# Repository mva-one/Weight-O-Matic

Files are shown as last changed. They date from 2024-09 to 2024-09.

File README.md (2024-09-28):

# Was ist Weight-O-Matic?
Weight-O-Matic ist ein kompaktes, einfach zu bedienendes, mikrocontrollergesteuertes Hilfsmittel auf Basis des AtMega 328P (Arduino Nano), um Prozesse, bei denen die Masse eines Objektes zunimmt, bei einem entsprechenden Soll-Wert anzuhalten. Es wurde speziell für den Anwendungsfall entwickelt, die Produktion einer Leitungswasser-Osmoseanlage anzuhalten, nachdem ein entsprechender Kanister am Ausgang vollständig gefüllt wurde.  

Das System bietet die Möglichkeit, das Gewicht des Wasserkanisters mittels einer Waage zu überwachen und entsprechend eines Sollwertes einen elektrischen Ausgang anzusteuern. In diesem Anwendungsfall ist an den Ausgang ein (stromlos geschlossenes) Magnetventil angeschlossen, welches den Wasserausgang der Osmoseanlage schließt - wodurch sich diese ausschaltet.

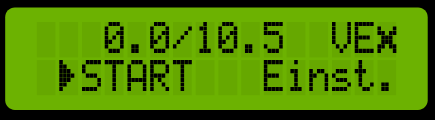
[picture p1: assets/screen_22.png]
Startbildschrim


***Hinweis:** Das Projekt ist aktuell noch Work-In-Progess! Es könnten noch weitreichende Änderungen erfolgen.*

# Was ist in diesem Repo?
Hier befinden sich alle Projektdateien:
- Im Unterordner `Weight-O-Matic_FW` ist das PlatformIO-Projekt für die Firmware des Mikrocontrollers zu finden.
<!-- - Der Ordner `Bedienungsanleitung` beinhaltet ebendiese als pdf-Datei. Ist noch ziemlich unvollständig. -->
- Unter `Zustandsdiagramm` ist die [abstrakte Darstellung der Menüzustände](Zustandsdiagramm/state_diagram.png) im PlantUML-Format und als PNG zu finden.
- Im Ordner `Weight-O-Matic_HW` befindet sich der Schaltplan (KiCad-Projekt) bzw. weitere Informationen zur verwendeten Hardware.
- `assets` beinhaltet alle Artefakte, die von diesem Readme oder in der Bedienungsanleitung eingebunden werden.

# Wie kann man das ausprobieren?

Mit [Wokwi](https://wokwi.com/) kann Weight-O-Matic simuliert werden, um es auch ohne Hardware ausprobieren zu können!

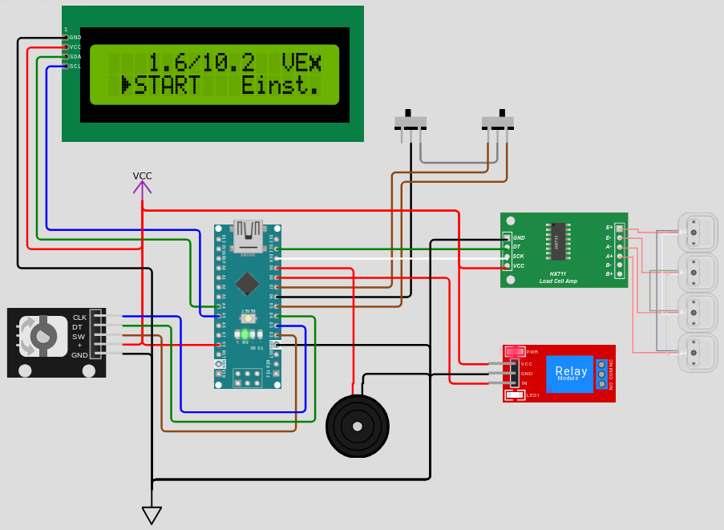
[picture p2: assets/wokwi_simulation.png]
Simulation mit Wokwi


Link: https://wokwi.com/projects/409734208353140737

**Hinweise zur Simulation mit Wokwi**:
- Manchmal wird beim Starten der Simulation ein Fehler angezeigt, da die Verbindung mit der simulierten Wiegezelle nicht hergestellt werden kann. In diesem Fall hilft das Drücken des Reset-Buttons auf dem Arduino Nano.
- Da Wokwi keine 3-Positionen-Schalter zur Verfügung stellt, ist der VE-Wahlschalter durch zwei separate Schalter dargestellt. Der linke wählt, ob eine VE aktiviert werden soll, der rechte Schalter wählt dann zwischen den zwei VE.
- Beim ersten Starten ist das EEPROM im Simulator nicht richtig initialisiert. Dann werden sinnlose Zahlen bei den Voreinstellungen als Tara-Versatz bzw. Sollwert angezeigt. In diesem Fall bitte einmal über das Einstellungsmenü den Punkt "RST" wählen, um das simulierte EEPROM mit den Standardwerten zu überschreiben. Da das danach folgende Software-Reset des Mikrocontrollers in der Simulation nicht funktioniert, ist der Reset-Button auf dem Arduino Nano zu betätigen!
- Die Standardwerte für die Kalibrierung der Waage sind für die Simulation ungeeignet. Am besten deshalb nach dem soeben beschriebenen Reset auch direkt eine Kalibrierung vornehmen!

# Lizenz

Siehe [LICENSE](LICENSE)!

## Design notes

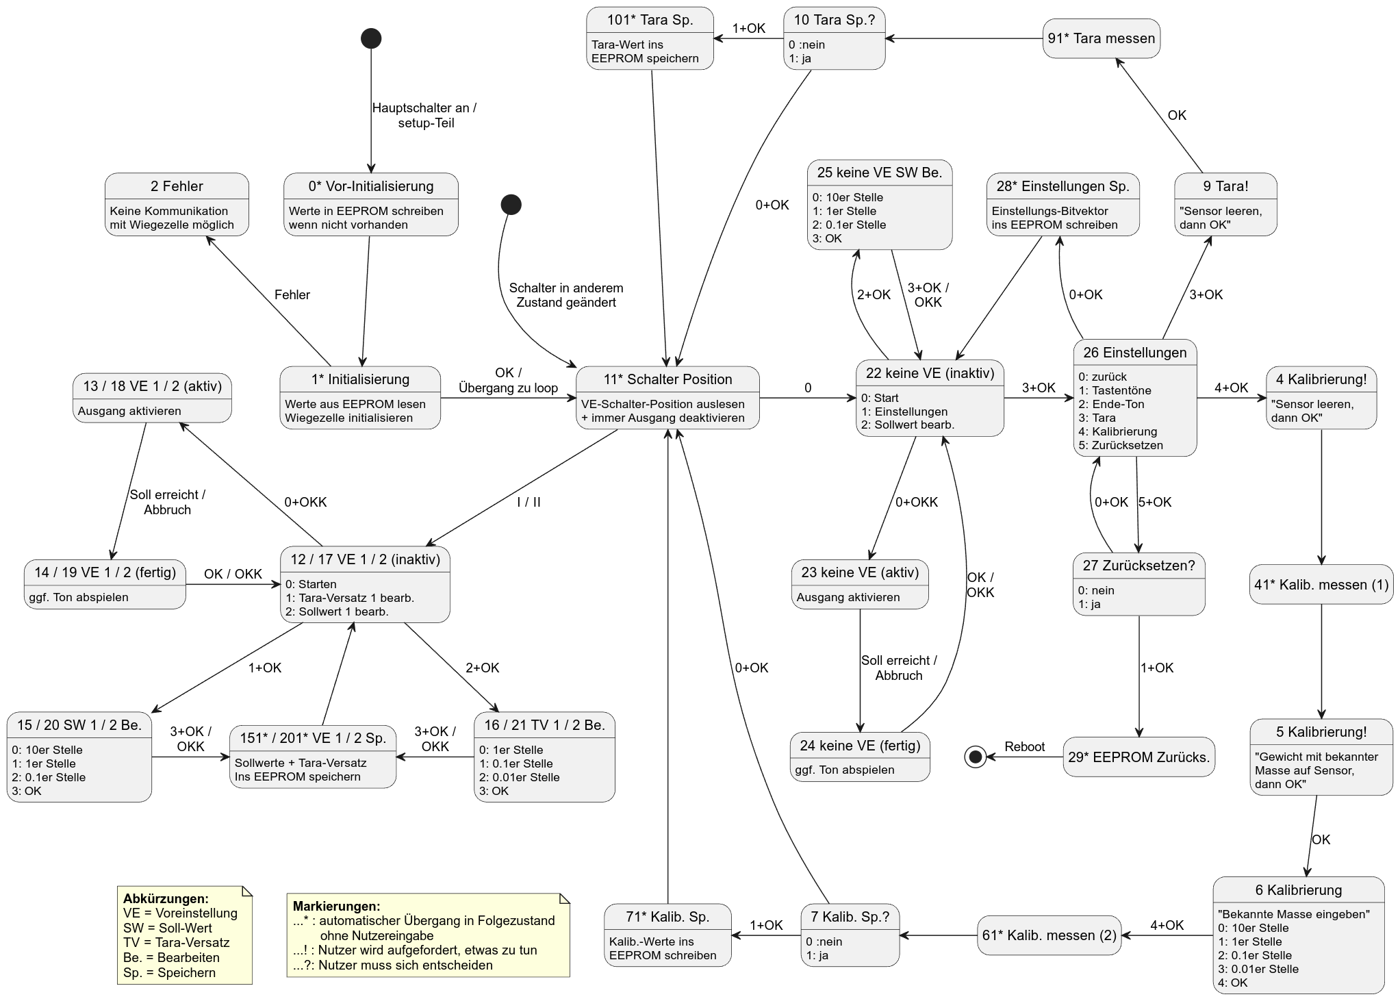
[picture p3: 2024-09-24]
Zustandsdiagramm/state_diagram.png

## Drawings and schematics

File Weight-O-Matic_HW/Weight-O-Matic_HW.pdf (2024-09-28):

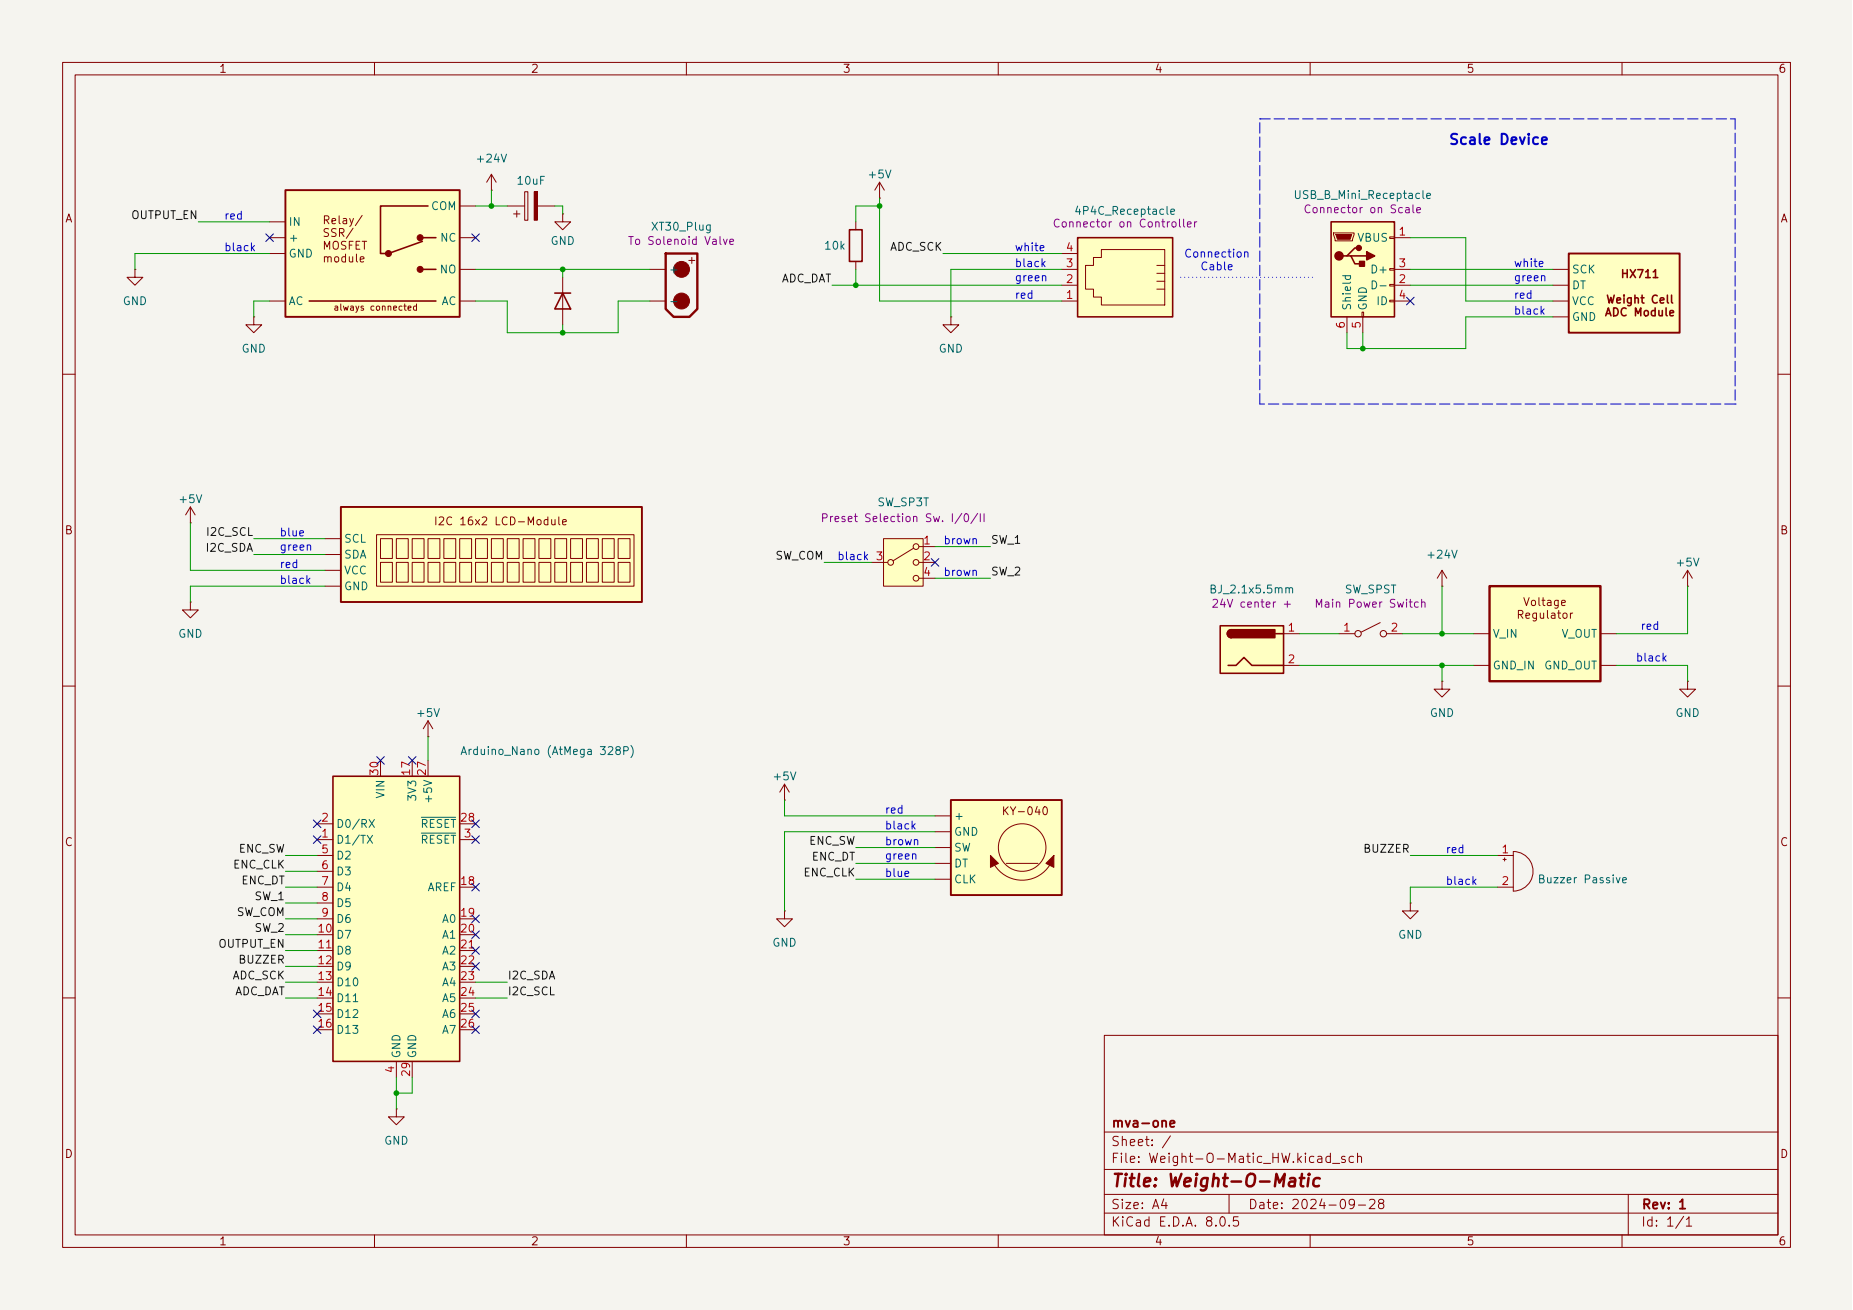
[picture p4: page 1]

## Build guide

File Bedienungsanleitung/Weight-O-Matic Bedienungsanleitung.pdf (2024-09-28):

# Weight-O-Matic Bedienungsanleitung Weight-O-Matic - Bedienungsanleitung

## 1 - Was ist Weight-O-Matic?

Weight-O-Matic ist ein kompaktes, einfach zu bedienendes Hilfsmittel, um Prozesse, bei denen die Masse eines Objektes zunimmt, bei einem entsprechenden Soll-Wert anzuhalten. Es wurde speziell für den Anwendungsfall entwickelt, die Produktion einer Leitungswasser-Osmoseanlage anzuhalten, nachdem ein entsprechender Kanister am Ausgang vollständig gefüllt wurde.

Das System bietet die Möglichkeit, das Gewicht des Wasserkanisters mittels einer Waage zu überwachen und entsprechend eines Sollwertes einen elektrischen Ausgang anzusteuern. In diesem Anwendungsfall ist an den Ausgang ein (stromlos geschlossenes) Magnetventil angeschlossen, welches den Wasserausgang der Osmoseanlage schließt - wodurch sich diese ausschaltet.

Im weiteren Verlauf der Anleitung wird dieser Anwendungsfall beschrieben.

## 2 - Komponentenübersicht

Das System besteht aus der Waage, dem Steuergerät und dem Magnetventil, sowie der dazugehörigen Anschlussleitungen.

## 2.1 Waage

Die Waage ist eine modifizierte handelsübliche Personenwaage. Das originale LC-Display der Waage hat keine Funktion. Auf der Unterseite befindet sich der Anschluss zur Verbindung mit dem Steuergerät: hierfür ist ausschließlich das beigelegte Kabel mit Mini-USB-Verbindern auf Seite der Waage und 4P/4C-Klickverbindern am Steuergerät

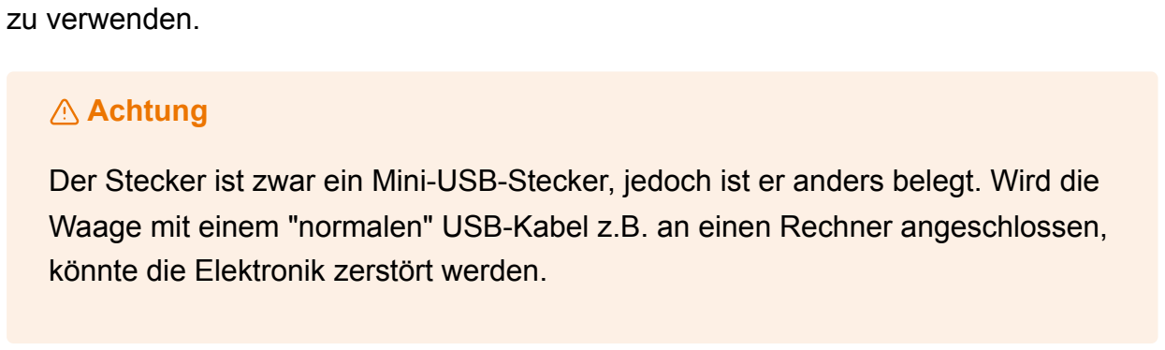
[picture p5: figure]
zu verwenden.; Achtung; könnte die Elektronik zerstört werden.

Der Stecker ist zwar ein Mini-USB-Stecker, jedoch ist er anders belegt. Wird die Waage mit einem "normalen" USB-Kabel z.B. an einen Rechner angeschlossen,

## 2.2 Steuergerät

Das Steuergerät ist die zentrale Komponente der Anlage. Zur Interaktion mit dem Nutzer stehen folgende Komponenten zur Verfügung:

Folgende Anschlüsse befinden sich am Steuergerät:

Seite | Typ | Verwendung
links | DC-Hohlstecker, 2.1x5.5mm | Stromversorgung der Anlage mit 24V DC (+ innen, -außen)
hinten | XT30-Stecker | Ausgang und Verbindung zum Magnetventil (24V DC)
hinten | 4C/4P "RJ-Stecker" | Verbindung zur Waage

## 3 - Funktionsprinzip

Das Grundprinzip ist einfach. Nach der Ersteinstellung (Kalibrierung, Tara-Versätze, Sollwerte) wird die gewünschte Voreinstellung gewählt, der Wasserkanister auf die Waage gestellt und das System gestartet. Dann lässt es so lange den Kanister auf der Waage befüllen, bis die Soll-Füllmenge erreicht wurde und spielt dann - wenn aktiviert
- eine kleine Melodie.

## 3.0 Menü-Navigation

Das Menüsystem von Weight-O-Matic ist so aufgebaut, dass es intutiv mithilfe des Dreh-Drück-Schalters bedient werden kann. Drehen bewegt den Cursor, um einen Menüpunkt auszuwählen und ein Klick aktiviert ihn. Bei Zahleneingaben erhöht bzw. verringert das Drehen die entsprechende Stelle der bearbeiteten Zahl und ein Klick fährt zur nächsten Stelle fort.

## 3.1 Voreinstellungen

Mit dem Voreinstellungs-Wahlschalter kann zwischen den zwei Voreinstellungen gewählt werden. Diese sind für zwei verschiedene Kanister(größen) vorgesehen. Pro

Ein-/Ausschalter
Voreinstellungs-Wahlschalter: siehe 3.1
Dreh-Drück-Knopf: dient der Navigation in allen Menüs. Kann kurz oder lang gedrückt werden, um verschiedene Funktionen auszulösen
LCD-Anzeige

Voreinstellung lässt sich ein Tara-Versatz im System speichern - das Leergewicht des Kanisters. Außerdem speichert Weight-O-Matic pro Voreinstellung die maximale Füllmenge des Kanisters.

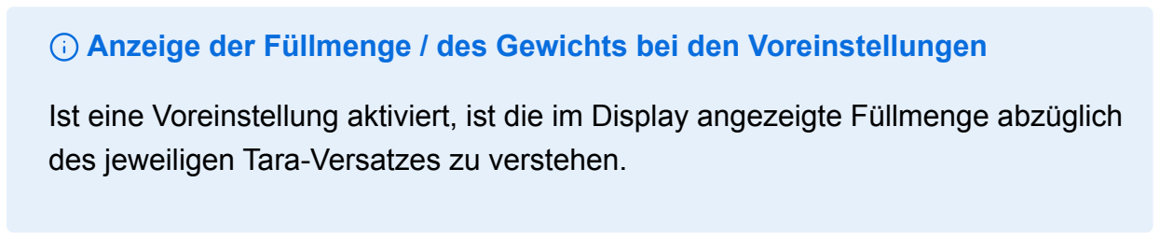
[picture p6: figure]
des jeweiligen Tara-Versatzes zu verstehen.

Wird eine Voreinstellung gestartet, sorgt Weight-O-Matic dafür, dass im Kanister so viel Wasser ist, wie im Soll-Füllwert angegeben. Insbesondere heißt das, dass die Voreinstellungen auch genutzt werden können, um Kanister bis zum Soll-Füllwert zu füllen, auch wenn diese nicht leer sind.

Voreinstellungen bearbeiten:
Es wird immer die Voreinstellung bearbeitet, die gerade durch den Voreinstellungs-Wahlschalter ausgewählt ist. Pro Voreinstellung kann der Sollwert und der Tara-Versatz, wie unter 3.0 beschrieben, bearbeitet werden.

Voreinstellung starten (aktivieren):
Weight-O-Matic kann aktiviert werden, indem der Menücursor auf "starten" bewegt wird und der Dreh-Drück-Taster lange gedrückt wird.

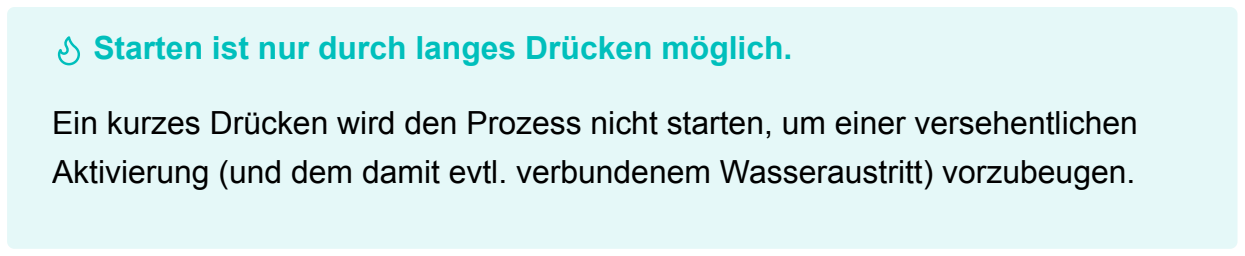
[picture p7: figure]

## 3.2 Keine Voreinstellung

Ist keine Voreinstellung gewählt (VE-Wahlschalter in Position "0"), so gibt es keinen Tara-Versatz, sondern nur einen Sollwert für den Füllprozess.

## 3.3 Füllprozess abbrechen oder beenden

Ist der Füllprozess aktiv, beendet sich dieser selbstständig, sobald der Sollwert erreicht ist. Bei Bedarf kann der Prozess auch durch Klicken des Dreh-Drück-Schalters abgebrochen werden.

In beiden Fällen wird anschließend eine Zusammenfassung angezeigt, wie viel Füllmenge erreicht wurde und wie lange der Prozess gedauert hat.

Anzeige der Füllmenge / des Gewichts bei den Voreinstellungen

Ist eine Voreinstellung aktiviert, ist die im Display angezeigte Füllmenge abzüglich

Starten ist nur durch langes Drücken möglich.

Ein kurzes Drücken wird den Prozess nicht starten, um einer versehentlichen Aktivierung (und dem damit evtl. verbundenem Wasseraustritt) vorzubeugen.

## 4 - Einstellungen

Die Einstellungen sind nur erreichbar, wenn keine Voreinstellung gewählt ist (VE-Wahlschalter in Position "0").

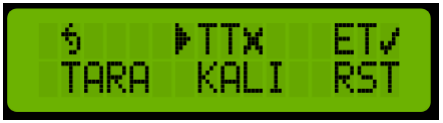
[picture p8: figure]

Das Einstellungsmenü bietet folgende Möglichkeiten:

TT aktiv / inaktiv: Tastentöne (Piepsen) ein- bzw. ausschalten
ET aktiv / inaktiv: Melodie beim erreichen des Sollwertes abspielen bzw. nicht abspielen
TARA: Waage Tarieren (ACHTUNG: Diese Tarierung gilt auch für die Voreinstellungen, bei denen zusätzlich noch der jeweils eingestellte Tara-Versatz hinzugerechnet wird)
KALI: Waage Kalibrieren. Hierzu werden die weiteren Schritte im Display angezeigt.
RST: Alle gespeicherten Einstellungen (auch Kalibrierungs- und Tara-Werte) auf die Standardwerte zurücksetzen. Dies ist normalerweise nicht nötig.

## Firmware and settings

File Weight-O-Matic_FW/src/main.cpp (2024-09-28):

/* MIT License

Copyright (c) 2024 mva-one

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
THE SOFTWARE IS PROVIDED "AS IS", WITHOUT WARRANTY OF ANY KIND, EXPRESS OR
IMPLIED, INCLUDING BUT NOT LIMITED TO THE WARRANTIES OF MERCHANTABILITY,
FITNESS FOR A PARTICULAR PURPOSE AND NONINFRINGEMENT. IN NO EVENT SHALL THE
AUTHORS OR COPYRIGHT HOLDERS BE LIABLE FOR ANY CLAIM, DAMAGES OR OTHER
LIABILITY, WHETHER IN AN ACTION OF CONTRACT, TORT OR OTHERWISE, ARISING FROM,
OUT OF OR IN CONNECTION WITH THE SOFTWARE OR THE USE OR OTHER DEALINGS IN THE
SOFTWARE.
 */

#include <Arduino.h>
#include <HX711_ADC.h>
#include <EEPROM.h>
#include <LCD_I2C.h>
#include <Wire.h>
#include <CtrlBtn.h>
#include <CtrlEnc.h>

#define VERSION F("v0.8")

#define PIN_BEEP 9              // 9 <-(rot)-> Piepser
#define PIN_SW_1 5              // 5 <-(braun)-> Schalter 'I'
#define PIN_SW_COM 6            // 6 <-(schwarz)-> Schalter Common
#define PIN_SW_2 7              // 7 <-(braun)-> Schalter 'II'
#define PIN_OUTPUT 8            // 8 <-(rot)-> Schaltmodul
#define PIN_HX711_DAT 11        // 11 <-(grün)-> DT HX711
#define PIN_HX711_SCK 10        // 10 <-(weiß)-> SCK HX711
#define PIN_ENCODER_CLK 3       // 3 <-(blau)-> CLK Dreh/Drückschalter
#define PIN_ENCODER_DAT 4       // 4 <-(grün)-> DAT Dreh/Drückschalter
#define PIN_ENCODER_BTN 2       // 2<-(braun)-> SW Dreh/Drückschalter
// I2C Pins sind default:       // A5 <-(blau)-> SCL     A4 <-(grün)-> SDA  

// Tonhöhen und -Längen für Tastentöne
#define BEEP_FREQ_LEFT 1350
#define BEEP_FREQ_RIGHT 1100
#define BEEP_FREQ_CLICK 925
#define BEEP_FREQ_ERR 440
#define BEEP_LENGTH_TURN 15
#define BEEP_LENGTH_SHORT 40
#define BEEP_LENGTH_LONG 250
#define BEEP_LENGTH_ERR 300

// Tonhöhen in Hz und "Takt" für Ende-Melodie
#define BEEP_FREQ_A5 880
#define BEEP_FREQ_F5 698
#define BEEP_FREQ_G5 784
#define BEEP_FREQ_B5 932
#define BEEP_UNIT_LENGTH 62
#define BEEP_END_REPETITIONS 4  // Wiederholungen der Ende-Melodie -> bei 4 Wiederholungen wird 5mal abgespielt

// Debug-Ausgaben über die Serielle Konsole aktivieren (Baud 115200)
#define SERIAL_ENABLED

// Standardwerte, werden bei leerem EEPROM geladen (z.B. auch nach dem Zurücksetzen über das Menü)
#define DEFAULT_WEIGHT_TARGET_NO_PRESET 4200
#define DEFAULT_CAL_FACTOR 28.44
#define DEFAULT_TAR_OFFSET 8240259
#define DEFAULT_P1_TARGET 5000
#define DEFAULT_P1_OFFSET 1000
#define DEFAULT_P2_TARGET 10000
#define DEFAULT_P2_OFFSET 2000
#define DEFAULT_TOGGLESETTINGS 0b11000000

#define MAX_WEIGHT_CALIB 99990
#define MIN_WEIGHT_CALIB 10
#define MAX_WEIGHT_SETPOINT 99990
#define MIN_WEIGHT_SETPOINT 100
#define MIN_WEIGHT_OFFSET 0
#define MAX_WEIGHT_OFFSET 9990

#define SETTINGS_KEYTONE 7
#define SETTINGS_ENDTONE 6


// EEPROM-Adressen für verschiedene Einstellungen:
const uint16_t addr_cal_value = 0x10;   // data type: float (4 bytes)  - addr. 0x10 - 0x13
const uint16_t addr_tar_value = 0x14;   // data type: long  (4 bytes)  - addr. 0x14 - 0x17
const uint16_t addr_saved_flag = 0x18;  // data type: bool  (1 byte)   - addr. 0x18

const uint16_t addr_p1_target = 0x20;       // stores long (4B) - addr. 0x20 - 0x23
const uint16_t addr_p1_offset = 0x24;       // stores long (4B) - addr. 0x24 - 0x27
const uint16_t addr_p1_saved_flag = 0x28;   // stores bool (1B) - addr. 0x28

const uint16_t addr_p2_target = 0x29;       // stores long (4B) - addr. 0x29 - 0x2c
const uint16_t addr_p2_offset = 0x2d;       // stores long (4B) - addr. 0x2d - 0x30
const uint16_t addr_p2_saved_flag = 0x31;   // stores bool (1B) - addr. 0x31

const uint16_t addr_toggle_settings = 0x32;       // stores byte      - addr. 0x32
const uint16_t addr_settings_saved_flag = 0x33;   // stores bool (1B) - addr. 0x33

// Intervall (ms) zum Auslesen des VE-Schalters
const uint32_t t_intv_switch = 276;

// Mindest-Intervall (ms) für die Display-Aktualisierung 
const uint32_t t_intv_screen = 100; 

// Timeout (ms) für Kommunikation mit Wiegezelle
const uint32_t t_timeout_weight_reading = 2024;


long current_weight_g = 13420;

long p1_target_g = 11000;
bool p1_target_ok = true;
long p1_tara_offset_g = 1110;
bool p1_tara_offset_ok = true;

long p2_target_g = 22000;
bool p2_target_ok = true;
long p2_tara_offset_g = 2200;
bool p2_tara_offset_ok = true;

long p0_target_g = DEFAULT_WEIGHT_TARGET_NO_PRESET;
bool p0_target_ok = true;

long last_target_g = 0;
long last_target_done_g = 0;
long t_last_target_started = 0;
long t_last_target_duration = 0;

long cal_known_mass_g = 1550;
bool cal_known_mass_ok = true;

uint8_t sw_pos = 0;
uint8_t sw_pos_pre = 0;
bool sw_event = false;

// Audio
bool use_keytones = true;
bool use_endtone = true;
int endtone_repetitions_done = 0;

// LCD-Menü und Zustände
bool redraw_screen = true;
uint8_t state = 0;
uint8_t sub_state = 0;
/* 
    Anmerkung des Entwicklers:
      Ja, die Zustandsnummern sind teilweise einfach völlig durcheinander. 
      Ja, das ist "historisch gewachsen"... ;)
      Aber es funktioniert und ich will es nicht ändern.
 */

// Status-Flag, ob der Ausgang aktiviert ist.
bool output_enabled = true;

// Hardware aus Libraries
HX711_ADC loadcell  (PIN_HX711_DAT, PIN_HX711_SCK);
LCD_I2C   lcd       (0x27, 16, 2);

// quick and dirty ;)
unsigned int pow10(unsigned int exponent) {
  static unsigned int pow10[10] = {1, 10, 100, 1000, 10000};
  return pow10[exponent]; 
}

// Einfache Prozedur für Software-Reset
void(* reset_function) (void) = 0;

void disableOutput() {
  digitalWrite(PIN_OUTPUT, LOW);
  output_enabled = false;
  #ifdef SERIAL_ENABLED
  Serial.println("Ausgang deaktiviert.");
  #endif
}

void enableOutput() {
  output_enabled = true;
  digitalWrite(PIN_OUTPUT, HIGH);
  #ifdef SERIAL_ENABLED
  Serial.println("Ausgang aktiviert.");
  #endif
}

// Einstellungs-Bitvektor aus den aktuell aktiven Einstellungen erstellen
uint8_t getToggleSettingsFromState() {
  uint8_t settings_bitvector = 0;
  settings_bitvector = use_keytones ? settings_bitvector | 1 << SETTINGS_KEYTONE : settings_bitvector & ~ (1 << SETTINGS_KEYTONE);
  settings_bitvector = use_endtone ? settings_bitvector | 1 << SETTINGS_ENDTONE : settings_bitvector & ~ (1 << SETTINGS_ENDTONE);
  return settings_bitvector;
}

// Aktive Einstellungen aus Einstellungs-Bitvektor übernehmen
void setToggleSettingsFromBitvector(uint8_t settings_bitvector) {
  use_keytones = (settings_bitvector & (1 << SETTINGS_KEYTONE)) >> SETTINGS_KEYTONE;
  use_endtone = (settings_bitvector & (1 << SETTINGS_ENDTONE)) >> SETTINGS_ENDTONE;
}

void drawCurrentWeight(long* weigth, long* offset = nullptr) {
  static long w = 0;
  w = offset==nullptr ? *weigth : *weigth - *offset;
  lcd.setCursor(1,0);
  if (w < 0) {
    lcd.print(F("-"));
    w = 0 - w;
  }
  else lcd.print(F(" "));
  if (w >= 65536) {
    lcd.print(F("  "));
    lcd.setCursor(5,0);
    lcd.write(3);
  } else {    
    if (w / 10000 != 0) lcd.print(w / 10000); else lcd.write(' ');
    lcd.print(w % 10000 / 1000);
    lcd.setCursor(5,0);
    lcd.print(w % 1000 / 100);
  }  
}

void drawTragetWeight(long* target) {
  lcd.setCursor(7,0);
  // wenn man im Bearbeitungs-Modus ist, soll auch die führende 0 immer erscheinen!
  if (*target / 10000 != 0 || state==15 || state == 20 || state==25) 
    lcd.print(*target / 10000); 
  else lcd.write(' ');
  lcd.print(*target % 10000 / 1000);
  lcd.setCursor(10,0);
  lcd.print(*target % 1000 / 100);
}

void drawTaraOffsetValue(long* value) {
  lcd.setCursor(11,1);
  lcd.print(*value / 1000);
  lcd.setCursor(13,1);
  lcd.print(*value % 1000 / 100);
  lcd.print(*value % 100 / 10);
}

void drawScreenForState(uint8_t targetState) {
  lcd.clear();
  lcd.setCursor(0,0);
  lcd.noBlink();
  switch (targetState) {
    case 2: {
      lcd.print(F("  FEHLER!!  :(  "));
      lcd.setCursor(4,1);
      lcd.write(0);
      lcd.print(F(" RESET"));
      break;
    }
    case 4: 
    case 9: {
      lcd.println(F("Waage entlasten!"));
      lcd.print(F("(Tara)"));
      lcd.setCursor(8,1);
      lcd.write(0);
      lcd.print(F(" weiter"));
      break;
    }
    case 41: 
    case 61: 
    case 91: {
      lcd.println(F(" Bitte warten!  "));
      break;
    }
    case 5: {
      lcd.println(F("Bek. Masse aufl."));
      lcd.print(F("(Kal.)"));
      lcd.setCursor(8,1);
      lcd.write(0);
      lcd.print(F(" weiter"));
      break;
    }
    case 6: {
      lcd.print(F("Bekannte Masse:"));
      lcd.setCursor(1,1);
      lcd.write(0);
      break;
    }
    case 7:
    case 10: {
      if (targetState == 7) lcd.print(F("Kal. speichern?"));
      else lcd.print(F("Tara speichern?"));
      lcd.setCursor(3,1);
      lcd.print(F("Ja     Nein"));
      break;
    }
    case 12:
    case 17: {
      lcd.print(F("  --.-/--.-  VE"));
      if (targetState==12) lcd.write('1');
      else lcd.write('2');
      lcd.setCursor(0,1);
      lcd.print(F("  START  TV-.--"));
      redraw_screen = true;
      break;
    }
    case 22:
    case 25: {
      lcd.print(F("  --.-/--.-  VE"));
      lcd.write(2);
      lcd.setCursor(0,1);
      lcd.print(F("  START   Einst."));
      redraw_screen = true;
      break;
    }
    case 13:
    case 18:
    case 23: {
      lcd.print(F("  --.-/--.-  VE"));
      if (targetState==23) lcd.write(2);
      else if (targetState==13) lcd.write('1');
      else lcd.write('2');
      lcd.setCursor(0,1);
      lcd.print(F("  aktiv   STOPP!"));
      lcd.setCursor(9,1);
      lcd.write(0);
      redraw_screen = true;
      break;
    }
    case 14:
    case 19:
    case 24: {
      long secs = t_last_target_duration / 1000;
      lcd.write(1);
      lcd.print(F(" --.-/--.-  VE"));
      if (targetState==24) lcd.write(2);
      else if (targetState==14) lcd.write('1');
      else lcd.write('2');
      drawCurrentWeight(&last_target_done_g);
      drawTragetWeight(&last_target_g);
      lcd.setCursor(0,1);
      lcd.print(F("--min--s  fertig"));
      lcd.setCursor(0,1);
      if (secs > 5999) {
        lcd.write(' ');
        lcd.write(3);
      } else {
        if (secs/600 != 0) lcd.print(secs/600); else lcd.print(' ');
        lcd.print(secs % 600 / 60);
        lcd.setCursor(5,1);
        if (secs % 60 / 10 != 0) lcd.print(secs % 60 / 10); else lcd.print(' ');
        lcd.print(secs % 10);
      }      
      lcd.setCursor(9,1);
      lcd.write(0);
      redraw_screen = true;
      break;
    }
    case 26: {
      lcd.setCursor(1,0);
      lcd.write(4);
      lcd.setCursor(7,0);
      lcd.print(F("TT    ET"));
      lcd.setCursor(1,1);
      lcd.print(F("TARA  KALI  RST"));
      break;
    }
    case 27: {
      lcd.print(F(" ZURUECKSETZEN? "));
      lcd.setCursor(0,1);
      lcd.print(F("Sicher?  nee  ja"));
      break;
    }
  }
  redraw_screen = true;
}

void stateTransition(uint8_t targetState, uint8_t targetSubState = 0) {
  state = targetState;
  sub_state = targetSubState;

  #ifdef SERIAL_ENABLED
  Serial.print("State transition to ");
  Serial.println(state);
  #endif

  switch (targetState) {
    case 2: {
      tone(PIN_BEEP, BEEP_FREQ_ERR, BEEP_LENGTH_ERR);
    }
    case 4:
    case 5:
    case 6:
    case 7:
    case 9:
    case 10:
    case 12:
    case 13:
    case 14:
    case 17:
    case 18:
    case 19:
    case 22:
    case 23:
    case 24:
    case 26:
    case 27:
    case 41:
    case 61:
    case 91: {
      drawScreenForState(targetState);
      break;
    }
    case 15:
    case 16:
    case 20:
    case 21: {
      redraw_screen = true;
      break;
    }
    case 25: {
      p0_target_ok = true;
      redraw_screen = true;
      //drawScreenForState(25);
      break;
    }
  }
}
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
void loop() {
  static uint32_t t;
  t = millis();

  static uint32_t t_switch = 0;
  static uint32_t t_last_weight_reading = t;
  static uint32_t t_screen = 0;
  static uint32_t t_tone_started = 0;

  static float loadcell_reading = 0.0f;
  
  break_loop = false;

  // Messwert aus Wiegezelle auslesen
  if (loadcell.update()) {
    t_last_weight_reading = t;
    loadcell_reading = loadcell.getData();
    if (loadcell_reading < -65536) current_weight_g = -65536;
    else if (loadcell_reading > 65536) current_weight_g = 65536;
    else if (current_weight_g != (long)loadcell_reading) {
      current_weight_g = (long)loadcell_reading;
      redraw_screen = true;
    }
  }

  // wenn zu lange kein Messwert mehr gelesen wurde --> Fehlerzustand
  if (t - t_last_weight_reading > t_timeout_weight_reading && state != 2) stateTransition(2);

  // process current state
  switch (state) {
    case 11: { // check switch state, then move to resp. next state
      disableOutput();

      static uint8_t sw_pos = 0;
      if (digitalRead(PIN_SW_1) == LOW) sw_pos = 1;
      else if (digitalRead(PIN_SW_2) == LOW) sw_pos = 2;
      else sw_pos = 0;

      switch (sw_pos) {
        case 0: { stateTransition(22); break; }
        case 1: { stateTransition(12); break; }
        case 2: { stateTransition(17); break; }
      }
      break_loop = true;
      break;
    }
    case 13: {
      last_target_done_g = current_weight_g - p1_tara_offset_g;
      t_last_target_duration = t - t_last_target_started;
      if (current_weight_g - p1_tara_offset_g >= p1_target_g) stateTransition(14, 1);
      else if (!output_enabled && current_weight_g - p1_tara_offset_g < p1_target_g) {
        t_last_target_started = t;
        last_target_g = p1_target_g;
        enableOutput();
      }
      break;
    }
    case 18: {
      last_target_done_g = current_weight_g - p2_tara_offset_g;
      t_last_target_duration = t - t_last_target_started;
      if (current_weight_g - p2_tara_offset_g >= p2_target_g) stateTransition(19, 1); 
      else if (!output_enabled && current_weight_g - p2_tara_offset_g < p2_target_g) {
        t_last_target_started = t;
        last_target_g = p2_target_g;
        enableOutput();
      }
      break;
    }
    case 23: {
      last_target_done_g = current_weight_g;
      t_last_target_duration = t - t_last_target_started;
      if (current_weight_g >= p0_target_g) stateTransition(24, 1);
      else if (!output_enabled && current_weight_g < p0_target_g) {
        t_last_target_started = t;
        last_target_g = p0_target_g;
        enableOutput();
      }
      break;
    }
    case 14:
    case 19:
    case 24: { // in diesen Zuständen ist die Dosierung regulär beendet und es wird die "Ende-Musik" gespielt. Könnte man sicherlich schöner programmieren! ;)
      if (sub_state > 0 && use_endtone) {
        switch (sub_state) {
          case 1: { t_tone_started = t; tone(PIN_BEEP, BEEP_FREQ_A5, BEEP_UNIT_LENGTH); sub_state++; break; }
          case 2: { if (t-t_tone_started>=BEEP_UNIT_LENGTH*4) {t_tone_started = t; tone(PIN_BEEP, BEEP_FREQ_F5, BEEP_UNIT_LENGTH); sub_state++;} break; }
          case 3: { if (t-t_tone_started>=BEEP_UNIT_LENGTH*2) {t_tone_started = t; tone(PIN_BEEP, BEEP_FREQ_F5, BEEP_UNIT_LENGTH); sub_state++;} break; }
          case 4: { if (t-t_tone_started>=BEEP_UNIT_LENGTH*2) {t_tone_started = t; tone(PIN_BEEP, BEEP_FREQ_G5, BEEP_UNIT_LENGTH); sub_state++;} break; }
          case 5: { if (t-t_tone_started>=BEEP_UNIT_LENGTH*4) {t_tone_started = t; tone(PIN_BEEP, BEEP_FREQ_F5, BEEP_UNIT_LENGTH); sub_state++;} break; }
          case 6: { if (t-t_tone_started>=BEEP_UNIT_LENGTH*8) {t_tone_started = t; tone(PIN_BEEP, BEEP_FREQ_A5, BEEP_UNIT_LENGTH); sub_state++;} break; }
          case 7: { if (t-t_tone_started>=BEEP_UNIT_LENGTH*4) {t_tone_started = t; tone(PIN_BEEP, BEEP_FREQ_B5, BEEP_UNIT_LENGTH*4); sub_state++;} break; }          
          case 8: { if (t-t_tone_started>=BEEP_UNIT_LENGTH*16) {t_tone_started = t; tone(PIN_BEEP, BEEP_FREQ_A5*2, BEEP_UNIT_LENGTH); sub_state++;} break; }
          case 9: { if (t-t_tone_started>=BEEP_UNIT_LENGTH*4) {t_tone_started = t; tone(PIN_BEEP, BEEP_FREQ_F5*2, BEEP_UNIT_LENGTH); sub_state++;} break; }
          case 10: { if (t-t_tone_started>=BEEP_UNIT_LENGTH*2) {t_tone_started = t; tone(PIN_BEEP, BEEP_FREQ_F5*2, BEEP_UNIT_LENGTH); sub_state++;} break; }
          case 11: { if (t-t_tone_started>=BEEP_UNIT_LENGTH*2) {t_tone_started = t; tone(PIN_BEEP, BEEP_FREQ_G5*2, BEEP_UNIT_LENGTH); sub_state++;} break; }
          case 12: { if (t-t_tone_started>=BEEP_UNIT_LENGTH*4) {t_tone_started = t; tone(PIN_BEEP, BEEP_FREQ_F5*2, BEEP_UNIT_LENGTH); sub_state++;} break; }
          case 13: { if (t-t_tone_started>=BEEP_UNIT_LENGTH*8) {t_tone_started = t; tone(PIN_BEEP, BEEP_FREQ_A5*2, BEEP_UNIT_LENGTH); sub_state++;} break; }
          case 14: { if (t-t_tone_started>=BEEP_UNIT_LENGTH*4) {t_tone_started = t; tone(PIN_BEEP, BEEP_FREQ_B5*2, BEEP_UNIT_LENGTH*4); sub_state++;} break; }
          case 15: {
            if (t-t_tone_started>=BEEP_UNIT_LENGTH*32 && endtone_repetitions_done < BEEP_END_REPETITIONS) {
              sub_state = 1;
              endtone_repetitions_done++;
            } else if (endtone_repetitions_done >= BEEP_END_REPETITIONS) {
              sub_state = 0;
              endtone_repetitions_done = 0;
            }
            break;
          }
        }
      }
      break;
    }
    case 28: {
      uint8_t settings_new = getToggleSettingsFromState();
      EEPROM.put(addr_toggle_settings, settings_new);
      #ifdef SERIAL_ENABLED
      Serial.print(F("(28) Einstellungen im EEPROM gespeichert: "));
      Serial.println(settings_new, BIN);
      #endif
      stateTransition(22);
      break;
    }
    case 29: {
      for (uint16_t i = 0 ; i < EEPROM.length() ; i++) EEPROM.write(i, 0);
      #ifdef SERIAL_ENABLED
      Serial.println(F("(29) Es wurde alles zurückgesetzt. Starte neu..."));
      #endif
      reset_function();
    }
    case 41: {
      loadcell.update();
      loadcell.tare();
      long tar_value = loadcell.getTareOffset();
      loadcell.setTareOffset(tar_value);
      #ifdef SERIAL_ENABLED
      Serial.print(F("(41) Tara abgeschlossen. Neuer Wert für tara_offset: "));
      Serial.println(tar_value);
      #endif
      stateTransition(5);
      break;
    }
    case 61: {
      loadcell.update();
      loadcell.refreshDataSet();
      float cal_value = loadcell.getNewCalibration(cal_known_mass_g);
      #ifdef SERIAL_ENABLED
      Serial.print(F("(61) Kalibrierung abgeschlossen. Neuer Wert für cal_value: "));
      Serial.println(cal_value);
      #endif
      stateTransition(7);
      break;
    }
    case 71: {
      float cal_value = loadcell.getCalFactor();
      long tar_value = loadcell.getTareOffset();
      EEPROM.put(addr_cal_value, cal_value);
      EEPROM.put(addr_tar_value, tar_value);
      EEPROM.put(addr_saved_flag, (uint8_t)169);
      #ifdef SERIAL_ENABLED
      Serial.print(F("(71) Kalibrierungswerte im EEPROM gespeichert: "));
      Serial.print(cal_value);
      Serial.print(F(" / "));
      Serial.println(tar_value);
      #endif
      stateTransition(11);
      break;
    }
    case 91: {
      long tar_value = 0;
      loadcell.tare();
      tar_value = loadcell.getTareOffset();
      loadcell.setTareOffset(tar_value);
      #ifdef SERIAL_ENABLED
      Serial.print(F("(91) Tara abgeschlossen. Neuer Wert für tara_offset: "));
      Serial.println(tar_value);
      #endif
      stateTransition(10);
      break;
    }
    case 101: {
      long tar_value = loadcell.getTareOffset();
      EEPROM.put(addr_tar_value, tar_value);
      EEPROM.put(addr_saved_flag, (uint8_t)169);
      #ifdef SERIAL_ENABLED
      Serial.print(F("(101) Tara-Offset im EEPROM gespeichert: "));
      Serial.println(tar_value);
      #endif
      stateTransition(11);
      break;
    }
    case 151: {
      EEPROM.put(addr_p1_target, p1_target_g);
      EEPROM.put(addr_p1_offset, p1_tara_offset_g);
      #ifdef SERIAL_ENABLED
      Serial.print(F("(151) Sollwert / Tara-Versatz für VE 1 im EEPROM gespeichert: "));
      Serial.print(p1_target_g);
      Serial.print(F(" / "));
      Serial.println(p1_tara_offset_g);
      #endif
      stateTransition(12);
      break;
    }
    case 201: {
      EEPROM.put(addr_p2_target, p2_target_g);
      EEPROM.put(addr_p2_offset, p2_tara_offset_g);
      #ifdef SERIAL_ENABLED
      Serial.print(F("(201) Sollwert / Tara-Versatz für VE 2 im EEPROM gespeichert: "));
      Serial.print(p2_target_g);
      Serial.print(F(" / "));
      Serial.println(p2_tara_offset_g);
      #endif
      stateTransition(17);
      break;
    }
  }
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

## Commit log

2024-09-28 added hardware
    [Weight-O-Matic_HW.kicad_sch]
2024-09-28 renamed directory
    [Weight-O-Matic_HW.kicad_sch]
2024-09-28 small adjustments
    [Weight-O-Matic_HW.kicad_sch]
